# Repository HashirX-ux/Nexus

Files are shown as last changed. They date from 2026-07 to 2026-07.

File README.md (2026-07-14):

# Nexus


[]()
[]()
[]()
[]()

> A wireless 3x4 macropad i'm building to speed up my workflow. Hot-swap switches, per-key RGB, an OLED screen for status, and a rotary encoder for macros. Works wired or wireless.

---

## What is it?

Nexus is a custom 3x4 (12 key) macropad i designed mainly for shortcuts and repetitive commands i was tired of typing out. Built around a nice!nano v2 so it can do bluetooth LE, with USB-C as a backup if the battery dies or i just don't feel like pairing it again. 12 hot swap sockets, per key RGB underneath, an EC11 rotary encoder, and a little OLED that shows battery % and what its connected to.

(quick note to future me: the tagline used to say QMK somewhere, thats wrong, QMK doesnt really do BLE on this board properly so i switched to ZMK. fix that if you see it anywhere else)

## Why build it

Because reaching over to a full keyboard just to hit a macro or shortcut combo got annoying. If i build the layout, lighting and firmware myself it actually fits how i work instead of some generic layout someone else made.

---

## Status

Research + design phase mostly done, now just cleaning stuff up. Schematic and routing still need some touch ups here and there. Full build log with all the component reasoning is in [journal.md](./journal.md) if you wanna see why i picked what i picked (spoiler: half of it was just "this was in stock on lcsc").

- [x] Component research (MCU, diodes, switches, USB-C, passives)
- [x] Schematic design
- [x] PCB routing
- [x] PCB fabrication
- [x] Firmware pin mapping
- [x] Assembly
- [x] Case design

---

## Planned Specs

| Component | Choice |
|---|---|
| Layout | 3x4, 12 keys |
| MCU | nice!nano v2 (nRF52840) |
| Connectivity | Bluetooth LE (wireless) + USB-C (wired) |
| Switches | Hot-swap, MX-compatible (Kailh / Gateron / Cherry MX) |
| Matrix diodes | 1N4148 |
| RGB | Per-key, WS2812B |
| Encoder | EC11 rotary encoder |
| Display | OLED - battery % + connected device |
| Firmware | ZMK |
| USB | USB-C, USB 2.0 (480Mbps, 5V/500mA) |

---

```
```

Tried to keep this organized roughly the way hack club's [hardware codex shipping guide](https://codex.hackclub.com/shipping/101/) recommends - source files seperate from the manufacturing stuff so its easier for someone else to just grab and rebuild.

> If you dont wanna open kicad just to look at the board, theres a KiCanvas link so you can view it in browser:
> 

---

## Build log

Most of the actual thinking (datasheets i looked at, why i swapped parts, dumb mistakes i made along the way) is in [journal.md](./journal.md). Genuinely recommend reading it if your building something similar, its more useful than just staring at the BOM.

---

## Roadmap

1. finalize schematic (matrix wiring, rgb data line, oled i2c, encoder pins, reset button)
2. route + order the pcb
3. build/test zmk firmware against actual pin assignments (not just what i think they are)
4. design + print the case
5. assemble, flash, pair, hope it works first try

---

## How to build

### 1. order the PCB

1. go to [JLCPCB](https://jlcpcb.com)
2. upload [`Gerber.zip`](./Gerber.zip)
3. settings: 2 layer, FR-4, 1.6mm, HASL (or ENIG if your feeling fancy)
4. order the parts seperately with [`Nexus-BOM.csv`](./Nexus-BOM.csv) as your shopping list - digikey, lcsc, aliexpress all work fine

### 2. print the case

1. open [`cad/`](./cad) - print the `.stl` as is, or crack open the `.f3d` in fusion if you wanna change dimensions
2. 0.2mm layer height, ~20% infill is plenty, its just sitting on a desk not getting thrown around
3. test fit the plate BEFORE you solder anything, learned that one the hard way

### 3. assemble

1. solder the nice!nano v2 diodes resistors and other supprt parts per the [`pcb/`](./pcb) schematic
2. solder in the hot swap sockets, then just press the switches in, no soldering needed there
3. wire the oled, encoder and rgb chain per the pin notes in [`journal.md`](./journal.md)
4. seat the finished pcb intothe case

### 4. flash it

1. follow the zmk build steps in [`firmware/`](./firmware) (shield config + keymap)
2. double tap reset on the nice!nano to drop into UF2 bootloader mode
3. drag the compiled `.uf2` onto the drive that shows up
4. pair over bluetooth, or just plg it in over usb-c if you want wired

### 5. done

flip it over, look at the rgb for a bit, start binding macros. if somethings broken check [`journal.md`](./journal.md) first, saves time vs trying to figure it out from scratch again.

---

## BOM

ful parts list + links in [`Nexus-BOM.csv`](./Nexus-BOM.csv)

---

## Credits

- [ZMK Firmware](https://zmk.dev/)
- [nice!nano](https://nicekeyboards.com/nice-nano/)
- [nice!nano docs](https://nicekeyboards.com/docs/nice-nano/) - pinout + hardware ref, used this constantly

Built by **Hashir**

---

## License

MIT, see [LICENSE](./LICENSE)

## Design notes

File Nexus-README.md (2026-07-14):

# Nexus


[]()
[]()
[]()
[]()

> A wireless 3x4 mechanical macropad built to speed up your workflow. Hot-swap switches, per-key RGB, an OLED status screen, and a rotary encoder for macro control — wired or wireless.

---

## What is it?

Nexus is a custom 3x4 (12-key) macropad designed for productivity, shortcuts, and macros. It's built around a nice!nano v2 for wireless Bluetooth LE connectivity, with USB-C wired support as a fallback. It features 12 hot-swap key sockets under a per-key RGB array, plus a tactile EC11 rotary encoder and an OLED display for at-a-glance macro and connection status.

> **Note:** The original project tagline mentions QMK, but based on the build log the firmware direction is ZMK (needed for the nice!nano's BLE wireless support — QMK's BLE support doesn't target this board). Worth updating that tagline once you settle on a final direction.

## Why build it?

A dedicated macropad means shortcuts, macros, and repetitive commands live on their own set of keys — no reaching for a full keyboard's modifier combos. Building it from scratch means the layout, lighting, and firmware are all shaped around your own workflow.

---

## Status

This project is in the **research and design phase**. Component selection is done; PCB schematic and routing are still in progress. See [`journal.md`](./journal.md) for the full build log, including component research and reasoning for each part choice.

- [x] Component research (MCU, diodes, switches, USB-C, passives)
- [x] Schematic design
- [x] PCB routing
- [x] PCB fabrication
- [x] Firmware pin mapping
- [x] Assembly
- [x] Case design

---

## Planned Specs

| Component | Choice |
|---|---|
| Layout | 3x4, 12 keys |
| MCU | nice!nano v2 (nRF52840) |
| Connectivity | Bluetooth LE (wireless) + USB-C (wired) |
| Switches | Hot-swap, MX-compatible (Kailh / Gateron / Cherry MX) |
| Matrix diodes | 1N4148 |
| RGB | Per-key, WS2812B |
| Encoder | EC11 rotary encoder |
| Display | OLED — battery % and connected device status |
| Firmware | ZMK |
| USB | USB-C, USB 2.0 (480 Mbps, 5V/500mA) |

---

## Repository Structure

```
Nexus/
├── LICENSE
├── README.md
└── journal.md   # Build log: component research, decisions, reasoning
```

As the project progresses, this will likely grow to include:
```
├── pcb/         # KiCad schematic + PCB files
├── firmware/    # ZMK shield config, keymap, overlay
├── cad/         # Case design files
└── BOM.csv      # Bill of materials
```

---

## Build Log

The full day-by-day research process — component tradeoffs, datasheets referenced, and lessons learned along the way — lives in [`journal.md`](./journal.md). It's worth a read if you're building something similar and want the reasoning behind each part choice, not just the final BOM.

---

## Roadmap

1. Finalize schematic (matrix wiring, RGB data line, OLED I2C, encoder pins, reset button).
2. Route and order the PCB.
3. Build and test ZMK firmware against the real pin assignments.
4. Design and print/order the case.
5. Assemble, flash, and pair.

---

## Credits

- [ZMK Firmware](https://zmk.dev/) — open-source keyboard firmware
- [nice!nano](https://nicekeyboards.com/nice-nano/) — nRF52840 BLE module
- [nice!nano documentation](https://nicekeyboards.com/docs/nice-nano/) — pinout and hardware reference

Built by **Hashir**.

---

## License

Released under the [MIT License](./LICENSE).

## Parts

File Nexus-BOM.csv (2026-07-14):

Component | Spec | Qty | Est. Unit Price (USD) | Est. Line Total (USD) | Notes | Where to Source
MCU | nice!nano v2 (nRF52840) | 1 | $14.00 | $14.00 | BLE wireless + USB-C wired; brain of the board | nicekeyboards.com / AliExpress clone
Matrix diodes | 1N4148 (or 1N4148W SMD) | 12 | $0.03 | $0.36 | One per key; col2row direction per journal | LCSC / Mouser / AliExpress (packs of 100+)
Mechanical switches | MX-compatible (Kailh / Gateron / Cherry MX -- TBD) | 12 | $0.30 | $3.60 | Hot-swap so any 5-pin/3-pin MX switch works | Switch vendor of choice
Hot-swap sockets | Kailh hot-swap (MX compatible) | 12 | $0.10 | $1.20 | Sold in packs of 100+ | LCSC / AliExpress
Per-key RGB LEDs SK6812 Mini-E for lower profile) | 12 | $0.20 | $2.40 | One per key; confirm footprint (5050 vs Mini-E) before ordering PCB | LCSC / AliExpress
Rotary encoder | EC11 (with or without push switch) | 1 | $0.60 | $0.60 | Confirm detents/resolution before finalizing keymap | LCSC / AliExpress
OLED display | SSD1306 0.91" or 0.96" I2C (128x32 or 128x64) | 1 | $2.50 | $2.50 | Shows battery % and connected device per journal | AliExpress / Amazon
USB-C receptacle | 16-pin SMD (e.g. GCT USB4105 or equivalent) | 1 | $0.60 | $0.60 | For wired fallback mode | LCSC / AliExpress
Reset button | SMD tactile switch 3x4mm | 1 | $0.05 | $0.05 | Needed to put nice!nano into bootloader mode | LCSC / AliExpress
Decoupling capacitors | 100nF ceramic (0603/0805) | 4 | $0.02 | $0.08 | Power supply stabilization near MCU/OLED | LCSC / AliExpress
Bulk capacitor | 10uF ceramic or tantalum | 1 | $0.05 | $0.05 | Bulk decoupling for power rail | LCSC / AliExpress
LED data line resistor | 330-470 ohm (0603/0805) | 1 | $0.02 | $0.02 | Series resistor on WS2812B data line | LCSC / AliExpress
I2C pull-up resistors | 4.7k-10k ohm (0603/0805) | 2 | $0.02 | $0.04 | SDA/SCL pull-ups for OLED | LCSC / AliExpress
Battery (optional -- wireless use) | LiPo 3.7V 150-500mAh w/ JST PH2 | 1 | $4.00 | $4.00 | Not yet confirmed in journal -- needed if running BLE untethered | AliExpress / Adafruit
PCB fabrication | 2-layer FR-4 1.6mm HASL | 5 boards | $4.00 | $20.00 | Typical JLCPCB minimum order | JLCPCB / PCBWay
Keycaps | MX-compatible, 12-key set or pulled from a larger set | 12 | $0.30 | $3.60 | Blank or macro-labeled caps recommended | Any MX keycap vendor
Screws | M3 x 6-8mm | 8 | $0.05 | $0.40 | Case assembly | Local hardware / AliExpress
Standoffs | M3 x 4-6mm | 4 | $0.10 | $0.40 | Case assembly | Local hardware / AliExpress
TOTAL (est.) |  |  |  | ~$53.90 | Excludes case material/printing -- add once case design is finalized

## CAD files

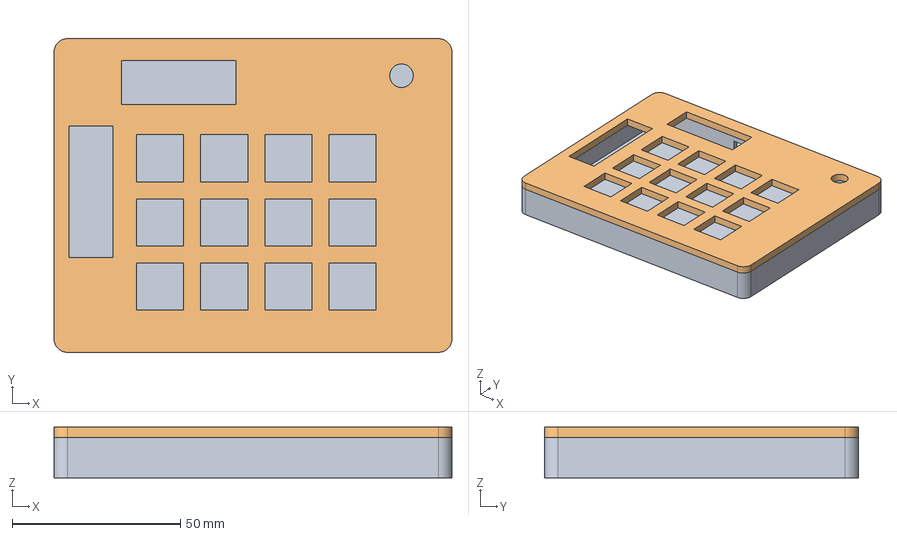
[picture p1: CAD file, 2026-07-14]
cad/Nexus-case.step
118.2 x 93.2 x 15.0 mm

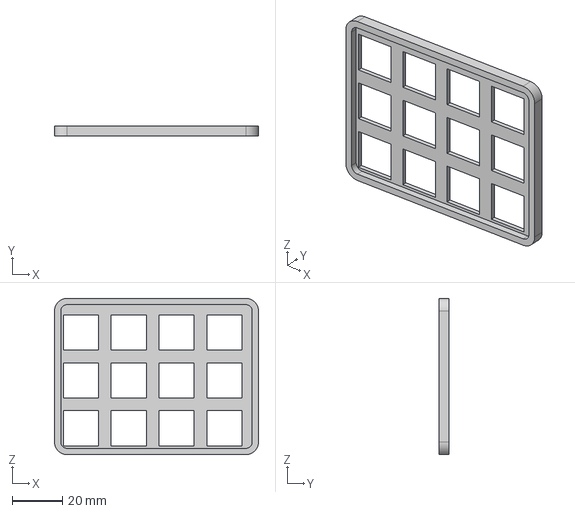
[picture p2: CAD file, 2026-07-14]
cad/Nexus-plate.step
81.3 x 4.10 x 62.2 mm

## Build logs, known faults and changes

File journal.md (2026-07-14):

# Project Journal

**Project Name:** Nexus  
**Start Date:** 2026-07-07  
**Status:** In Progress

## Overview
Nexus is a wireless 3x4 macropad built to optimize your workflow. It uses a nice!nano for Bluetooth LE. It features 12 hot-swap keys illuminated by a vibrant per-key RGB lighting array. A tactile EC11 rotary encoder and an OLED screen offer precise macro control. Powered by ZMK firmware, it brings seamless multi-device pairing anywhere you go.

## Recent Entries

### 2026-07-07 - First Journal Entry

**What I did today:**

I amn gonna start researching about my Macropad built for productivity named Nexus for it's components and elemensts. Since I have never created a macropad, It's gonna take a while.. 



Since I am making a productivity macropad, I need to use such MCU that supports wireless bluetooth capability. From My research I think nicenano-v2 would be best for my macropad 


<br>
> So I have summarized all the necessary components for a macropad. 
<br>
1- MCU -> nicenano!-v2 (It acts as the brain of the macropad and controls most all the operations)
<br>
2- Diodes(1N4148)
<br>
3- Mechanical Switches -> Gonna use Kalih or Gateron Switches and probably will consider Cherry MX)
<br>
USB-C(Gonna make it wired also) 
<br>
4- Capacitors and Resistors for Maintainance for powersupply

<br>
> I am gonna add some customs also for my macropad.
<br> 
1- OLED Display (Gonna show its battery percentage and connected devices) 
<br>
2- RGB lights(WS2812B) for Asthetics ifykyk
<br>
3- Rotary Encoder(EC11) No idea Why I am adding this (asthetics)
<br> 
<br>
Now I am gonna start researching about all the components one by one.. <br>
1- nicenano!<br>
Since nicenano has two versions I am gonna research about the latest one and use that.. <br>
Gonna use the official nicenano documentation for research about nicenan<br>
https://nicekeyboards.com/docs/nice-nano/<br>
This is how the nicenano pinouts look like: <br>

<br>
<br> 
So I gotta use ZMK firmware for my macropad since its wireless via bluetooth capability.. <br>
The Schematic looks intimidating but it's simple .. I guess<br>

<br>
<br>
Now I am gonna read some datasheets of the Diode (1N4148) specifically designed for macrpads and keybaords.. <br>
So these are the Diodes I am gonna be using<br>

<br> 
These diodes are really efficient for keebs and pads :D 
<br>
<br>
Now I am gonna research about the USB-C device that I am gonna use in my macropad cuase I wanna make my prodcutivity macroapd boht wired and wireless sor for wired capability I am gonna have to use USB-C<br>

Gonna use USB 2.0 as it provides 480 mps and takes 5V with 500mA

<br> 
Best Guide to Study USB-C:<br> 
https://www.ti.com/lit/eb/slyy228/slyy228.pdf?ts=1759892558029
<br>
Looks Like I am cooked :((

Now I think I have gained enough info about USB-C, Moving to the next componentttttttttt.
<br>
<br>
Now I am gonna start Researching about the capacitors and the resistors that are required for macropad and are essential for the Power Management accross the PCB<br>
Found a New component to research about: 

So bascially a crystal tells how fast the chip processes but I don't really have to build it since it comes pre-built with nicenano!-v2 chip so Im save :D:

<br>
<br>
Now I am gonna research about Capacitors that are needed in my macropad:<br>
Guess I don't need any caps at all except I think for my RGB lights.. 

<br>
<br>
I do have to also add a RESET button on my schematic for my nicenano! to go bootloader mode for my ZMK configuration: 

<br>
I also need some decoupling caps that are gonna stablise the power supply across the circuit: 

Fair Enough.. So I gotta maintain the power supply by at least adding one or more decoupling or bypass caps so that power accorss my Circuit stabilised in high and low voltages: 

<br>
Interesting.. 

<br>
Learned about a new concept called "impedance". Basically it refers to opposition a component or circuit offers to the AC: 

<br> 
Best Wbsites I have visited to study about Decoupling capacitors and value of 100nF and why is it important and what significance this specific value holds.. : 
<br>
https://pcbsync.com/100nf-capacitor/
<br>
https://learn.sparkfun.com/tutorials/capacitors/application-examples
<br>
<br> 
Now I am gonna start researching about the resistors that I need for my macropad:<br>
Looks like I don't really need the resisotrs for my macropad: 

<br>
But I think I do need them for my RGB lights for the key switches.. 

<br>
So the common resistors are 220 ohm and common caps are 100nF
<br>
nicenano! v2 gives the output login of 3.3V and take 5V from the USB input So i gotta be carefull before adding some resistors as they can limit the cuurent that is required by the RBG lights as they require much higher voltage(around 5V) so I only need to add like 1 resistors for every 2 RGB light to stablise the connection 
<br>
I also need a bulk Capacitor according to the lights I am gonna use which are RBG WS2812B

<br>
This is gonna store the voltage when the line surges or drops.. Interesting: 

<br>
THANK GODDD!!! IM SAVED.. I thought I would also need to build a voltage regulator for my macropad but I think I don't have to now :D

<br>
So the 330 ohms is the one I am targetting: 

<br>
<br> 
Now I am gonna research about the Rotary encoder I am gonna use for the macropad:<br>
So there are two rotary encoders am I am considering to use on of them.. One is PEC11R and the other encoder is EC11. I have researched and most of the resources recommend using the EC11 for a DIY- macropad cause it's the most industry standard and commonly used for macropads..

<br>
So this is the EC11 Rotary encoder: 

<br>
So the EC11 Rotary Encoder uses DC voltage of 3.3V which is perfect for my nicenano!-v2 MCU :D

<br>
<br> 
Now I am gonna start working on the KeySwitches of ny macropad:<br>
One of the best Guides I have read for the key  switches
https://www.theremingoat.com/blog/beginners-guide
<br>
So this is the Cherry MX switch. Looks pretty fine to me as it also metions that this key switch makes that "click" sound when you clikc it so I guess it's pretty cool :D

<br>
It seems pretty tempting to use Cherry MX keys.

<br>
Although Cherry MX keys looks a really good and reasonable choice, I am still gona search gonna search for more good and those "clicky" sound keys as I am reallt OBSSESED with them.. 
<br>
I think Kalih switches are also a really great Option to use but I gotta do a a liitle more research but I think i am considering to use Kailh swutches for my Macropad cause I think they look a little bit more beautifull than cheryy for some reason especially the kailh red switch is really attractive to use to I think I am gonna consider to use Kailh Switches and I have planned to use 12-key switches for my macropad and the matrix I am gonna use will be 3 x 4 :D
<br>
<br> 
Now I am gonna research about the battery that I am gonna use in my DIY-Macropad and for that I am gonna use nicenano! official documentation cause the have specified which battery to use to the Microcontroller.. 
<br>
https://nicekeyboards.com/docs/nice-nano/
<br>
Since I am also using the LED lights which is gonna take more power so I can't use the battery given in this documentation: 

<br>
Hence I am gonna use a 1500mAh battery for my DIY- Macropad. that is gonna help me maintain the electricty in the macropad when The bluetooth wireless capability is turned on .. 
<br>
This guide is really helpfull as it really helped to understand How schematics work and How I should design my own custom PCB and macropad :D. I didn't read it full though but gonna read it cuz its describes how pcb works and how to design their schematics :D<br>
https://github.com/ruiqimao/keyboard-pcb-guide#schematics
<br>
I researched about pull-up resistors and seems like I don't to place any external pullup resistors case nicenano! is TOOO GOATED!!!!!!!!. You can literally configure the power supply from the ZMK :D<br>
Here is the resource I used to read about the pullup resistors and it's really goated... :D<br>
https://learn.sparkfun.com/tutorials/pull-up-resistors<br> 
<br>
<br>
Since It's my firt time bulding a macropad so I am gonna read some of the guides on how to build that form absolute 00000000...
<br>
Found another guide on how to build a macropad form scratch. LET'S READDD<br>
https://medium.com/@timowielink/how-to-build-a-macropad-d5a154311c4c
<br>
The difference is I am gonna use a nicenano!-v2 microcontroller instead of ESP-32 MCU so I think there will be places Where I am gonna get stuck on This guide but let's hope for the best. :D
<br>
<br> 
Shoot.. I forgot to research about the OLED I am gonna use on my macropad. Lemme get that real quick:
<br>
I researched about which OLED to use and I came accross an OLED Which was also by nicenano! called niceview! and it seems pretty interesting since I have the same Microcontroller and as well as its OLED screen which it perfectlly suits.
<br>
https://nicekeyboards.com/docs/nice-view/pinout-schematic
<br>
This is the device I am planning to use as my OLED :D

<br>
And this is the schematic of the niceview!: 

<br>
This guy built a Macropad and open sources it:<br>
https://github.com/imchipwood/dumbpad
<br>
Found about these low profile switches .. Don't know what do they even do..

<br>
12C devices are quite interesting :D

<br>
A really good guide reguarding OLED and 12 protocol explanation..
<br>
https://blog.tinkercademy.com/deep-dive-into-the-i2c-oled-413fee46ada1
<br>
Ok I might consider using an OLED of 0.96": 

<br>
I am gonna search for some routing tips and I think I have found a great website for that.
<br>
https://www.pcbway.com/blog/PCB_Design_Layout/Common_Rules_for_PCB_Routing_29d86598.html
<br>
Didn't knew that greater loop would cause more heat and radiation during the routing of the PCB..

<br>
So i gotta make smaller loops in my routing so that I coukd avoid ekectromagnetic interference and unwanted noise.. 

<br>
I've found that de coupling capacitors help in reducing the electromagnetic interferance by maintaining the noise to signal ratio in the PCB so it's really a good practice to add bunch of those :D
and certainly 100nF is the best capacitor for balancing the pwoer in the PCB 
<br>
I also wanna learn about the 3D case design so I found an incredibally helpfull resouce to help me with that.. 
<br>
https://www.makerluis.com/step-by-step-guide-parametric-macro-pad-on-fusion-360/
<br>
I also found a video of this incredble Guy and he bascially gave a full tutorial on how one can design their own custom macropad case which is really helpfull. Hats off to this guy gng..
<br>
https://youtu.be/egOOHS-34-c?si=lpAW9fYHbgnp78mD
<br>
I think fusion 360 is currently the best 3d case software out there cause I have researched a lot on the 3d case for the macropad and Its showing me a fusion 360 tutorial every single time.. 
<br>
I Found the official hackclub's guide on designing a hackapad (Don't even know what that is) 
<br>
https://hackpad-v2-backup.pages.dev/guide#bottom
<br>
Since I am building a wired and wireless macropad I am gonna be using ZMK firmware for my macropad even though I have no idea what that even is in the first place So gonna research aobout it.. Wish me luck.. gang..
<br>
The ZMK docomentation is really helpfull for this :D
<br>
https://zmk.dev/docs/hardware
<br>
This guide is also really helpgull. Currently reading it ....
<br>
https://medium.com/@Myphis/zmk-firmware-unleashing-the-power-of-keyboard-customization-ed9fa9f8468e
<br>
So according to my summary QMK is for wired keyboards and ZMK is usually for wireless keyboards but ZMK can also be used for wired keyboards by having microcontrollers such as RP2040 wtc which I am not using for sure.. and I guess this is all I have to my today's journal and I am gonna write the next journal entry Tommorow :D

### 2026-10-08 - Second Journal Entry

**WHat I did Today:**
So Today I am gonna create the schematic of my Nexus aka macropad and its gonna be fun hopefully and I have already Researched about all the components that I need to build the schematic and Now I have to just make the schematic and then I'll be done with the schematic part. I am gonna build me schematic on KiCad.. 

<br>
I have created a keyboard type matrix for the macropad with a 3 x 4 matrix as I described earlier ny using a keyboard design guide from the resource https://www.nextpcb.com/blog/how-to-design-mechanical-keyboard-pcbs-with-kicad.. Looks cool to me. 

<br>
<br>
Now I am gonna start building the USB-C 2.0 16P schematic on the KiCad and it has a complete guide om how to set it up on the ncienano! official webiste and documentation so I am gonna read that real quick.. 
<br>
https://nicekeyboards.com/docs/nice-nano/pinout-schematic
<br>
I still can't figure out the function of the CC1 and CC2 pins of the USB-C 2.0 :((

<br>
Guess I am done with the USB-C configuration and Now I am gonna move to my next component..

<br>
<br>
Now with that being said I have somehow confiured my rotary encoder and have connected it to my Microcontroller and Now what it is gonna do is send signals to my macropad whenther it is getting pulled clockwise and will tell the microcontroller which in this case is nicenano! v2 to react in accordance to those signals 

<br>
<br>
Now I am gonna add a RESET switch and what it will gonna do is to make the Microcontroller, which in this case is nicenano, enter in a bootloader mode so that you can Literally drag and frop your ZMK firmware file in the USB device of the microcontrolle which will show up when it enters in the boot loader mode.. 
<br>

<br>
Just Found another helpfull resource for the Reset button guide :D
<br>
https://binaryupdates.com/switch-with-8051-microcontroller/
<br>
<br>
So Instead of using the classis 0.96" OLED, I used 0.91" OLED cause I couldn't find the symbol of the OLED 0.96" anywhere so I had to use OLED 0.91 but it's completely fine cause I guess 0.91" is more common among these DIY-macropads and I also cinfigured it in KiCad amd it's pretty simple :D

<br>
I have aslo creatd 2 decoupling caps for power management and they bascially manage the input power and high voltages that comes in the boara and these actually play a really vital role on the board :D

<br>
Now I am gonna add power management by thr battery cause my macropad is also wireless and as well as wired so I have researched and read what kind of battery Do I need form the nicenano"s official documentationa and its lithiu-Ion battery with 3.7V:
<br>
https://nicekeyboards.com/docs/nice-nano/
<br>
I think this is the battery that I need to store my power.. 

<br>
So I have used Conn_01x02 for my lithium battery and I also have set the capacity to 15500mAh which I think is decent for a macropad and I think it will makes my macropad atleast long lasting than those stupid Iphones(Saying that cause I can't afford one) 

<br>
For charging the battery I have used MCP73183-2-MC charger which is industry standard for Lithium-Ion batteries and It's also really easy to setup in the editing software which for me is KiCad :D

<br>
Nicenano! is super underated. I doon't even need a power regualtor to maintain my LED lights !!!!!!!!!!!!

<br>
Since my microcontroller which in this case is nicenano! outputs only 3.3V and my LEDs need like 5V of ouput voltage so I am gonna use a component which i found out which is 74AHCT123. This components bassically increases the voltage of the output 3.3 and makes it 5V and so its is really clear for my LEDs and I am gonna use this component: D

<br>
I also need to place a decoupling cap for my LED for it to be stable :D.. 

<br>
<br> 
Now I am gonna start Configuring out my MAIN BRAIN!!!! not literally I am talking about nicenano. I am gonna add all the new pins in the nicenano and then gonna configure it out.. 

<br>
I also gotta add the key matrix on my nicenano! chip.. 

<br>
Its kinda hard but I am still figuring it out.. 
<br>
Now I am gonna add some RGB Lights for my macropad keys but I gotta find how can I do that and study the function of the each pin of the LED so that I can easily connect it to my keys :D..

So this is how an LED is designed gng.. I think I am learning some great great stufffffff.. its just an LED brooo. anyways..

<br>
Done with the first Row gng. Now I gotta do 3 more rows so that it matches my matrix of 3 x 4. Then I'll have an LED for each of my key in the macropad and its gonna be dunn :D

<br>
Donw with 2 ROWSSS

<br>
So I have made thhe RGB key matrix and it looks really good to me :D. Now what's gonna happen is my keys of the macropad will have their own RBG lightining for them to shine.. YAYAYAYA

<br>
So I have also planned to add a buzzer so that it can also make those clicky sounds to make the macropad more satisfyign and addictive to use. SO I am GONNA MAKE YOU AN ADDICT HAHAHAHA

<br>
So Now I am gonna configure my whole schematic and make it look a more good and managable.. 
<br>
After Debugging SOO many erors running ERC like a madman, I finaly have 0 ERRORS!!!!!!!!!!!!!!!!!!

<br>
I still have 4 warnings but they dont matter gng.. hopefully

<br>
Gonna start arranging ts gng.. Wish me luck ...

<br>
LOOKS SOOO CLEAN... YAYYAYAYAY

<br>
It Even Looks more clean since I have named every Single component in the schematic.. 

<br>
GUYSSS ... After 11 DEVASTATING HRS.. I HAVE FINALYYY COMPLETED MY SCHEMATIC!!!!!!!!!!! YAYAYAYAYAYA



<br>
<br>
### 2026-09-07 - First Journal Entry

**What I did today:**
So Today I am gonna design the PCB of my macropad on the KiCad PCB editor and Its gonna be tough as I can see the diagram looks realy rough and I have to arrange EVERY single component of the schematic on this PCB editor sheet.. 

<br> 
I am gonna tsart by creating the keyboard matrix whohc consist of a push button of Kailh and RGB light and diodes and Caps of 100nF

<br>
So I am Finally Done with the keyboard matrix gng.. It look good to me.. I mean it's simple but its my first macropad.. DONT JUDGE MEEEEE!!!

<br>
MY FIRST MACROPAD DESIGN GANGGGGG!!!!!!!!!!!

<br>
Alomost done with the routing. I gotta route some more components and then I think I'll be done with the Riuting and then I am gonna do Design Rule check for my macropad and then FIX ALL the errors. So I think I have to invest like something around 5 hours more in it. It's taking sooooo long gng.. Wish me luck.. 

<br>
SOOO MANY ERRORSS!!!!!!!!!!!!!!!!!!

<br>
AYAYAYAYAYAYAYAYAYA!!!!!!!!!!!

<br>
Bro SOMEHOW I have 19 WARNINGS EVENTHOUGH I did absolutly nothing and here we go.. This app ragebaiting me fr...
****
<br>
All of this shoot just cause the components names are too "BIG" gng what the absolute hell 

<br>
I found github repository where all the necessary 3d models of keyboards.. IT'S SOOO GOATEDDDD!!!!!!!!
<br>
https://github.com/raulmoracode/Kiboar
<br>
UHHH .. HELLO????

<br>
FINALLY I CHANGED THE AXISSS.. god it was hard. It took sooo much accuracy to reach this lvl..


<br>
Gonna Use this github repository for my Kailh hotswap switches.. It tool sooooooooooooooooooo much browsing to search fot this golden repositor. It has all the 3D models gng :D 
<br>
https://github.com/raulmoracode/Kiboar
<br>
FINALY DONE WITH THE PCB!!!!!!!!!!!!!!!!!!!!!!!!!!!!!!!!!!!!!

<br>
<br>
### Second Journal Entry  2026-11-12

** What I did Today: **
So today I am gonna design my 3D case of my Macropad and I am gonna do that by using fusion 360 cause I have used it before and I know more than the basics so It should be easy.. WISH ME LUCK BOYSS.. 

<br>
So I Just created a 3d modela reference and so far it looks good to me
<br>
Sorry forgot to journal this part but I made the layout and its pretty decent i guesss
![Uploading image.png…]()

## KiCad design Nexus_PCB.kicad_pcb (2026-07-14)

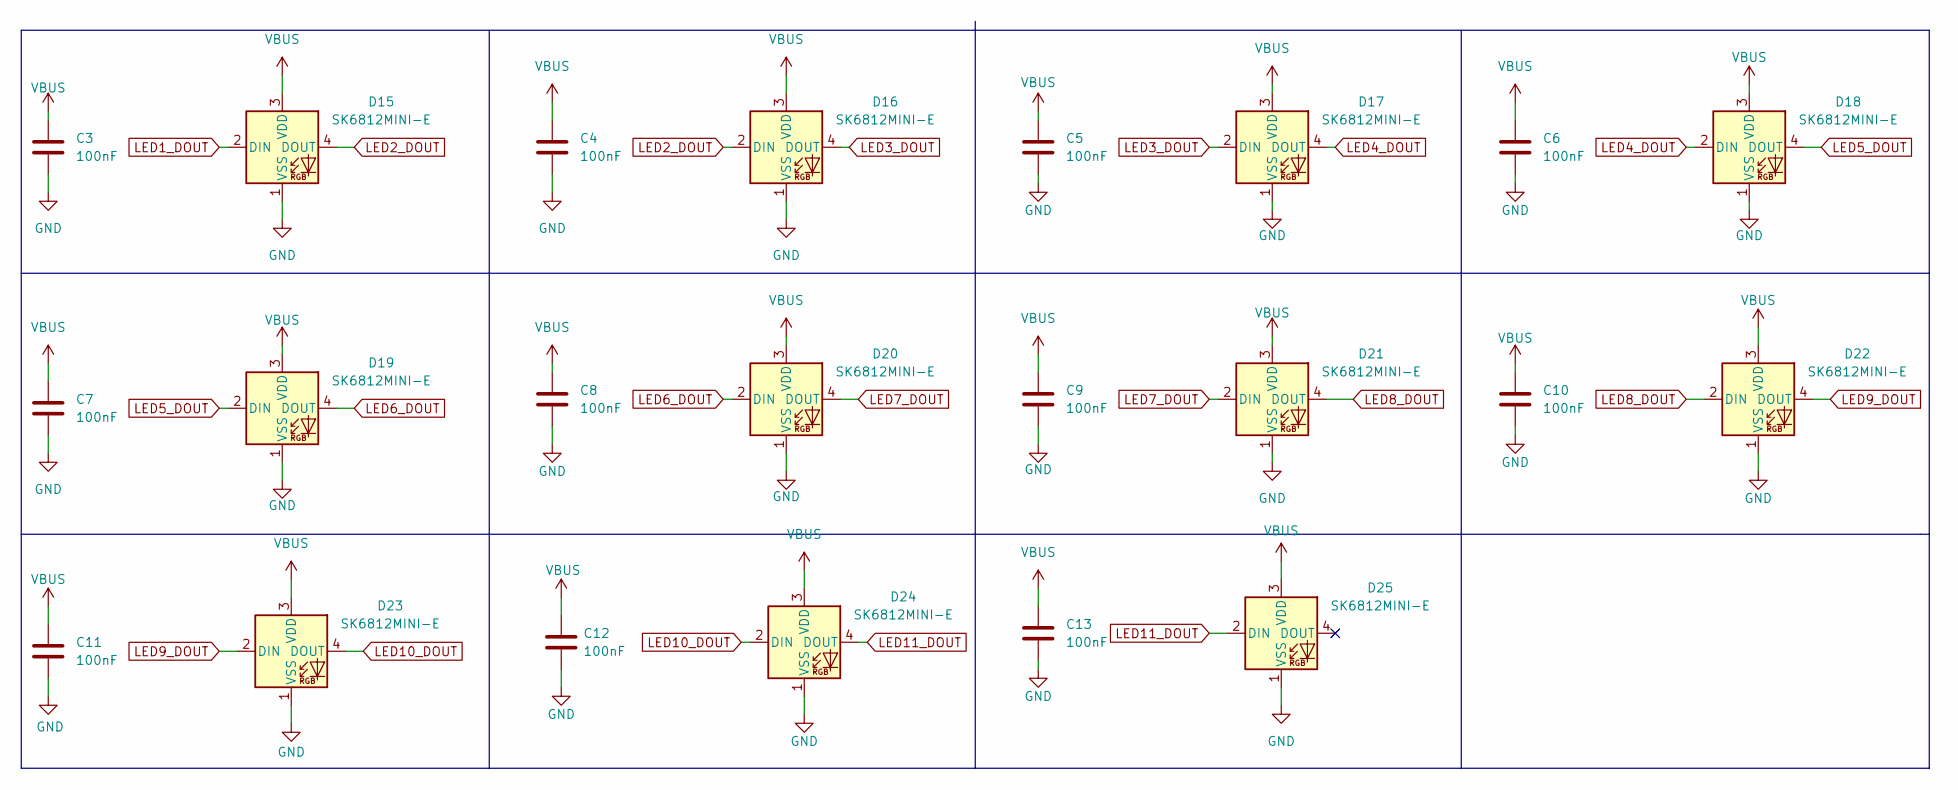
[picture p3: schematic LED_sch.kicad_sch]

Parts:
C3, C4, C5, C6, C7, C8, C9, C10, C11, C12, C13: 100nF; C_0805_2012Metric_Pad1.18x1.45mm_HandSolder
D15, D16, D17, D18, D19, D20, D21, D22, D23, D24, D25: SK6812MINI-E; LED_SK6812MINI-E_3.2x2.8mm_P1.5mm_ReverseMount

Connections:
GND: C3.2, C4.2, C5.2, C6.2, C7.2, C8.2, C9.2, C10.2, C11.2, C12.2, C13.2, D15.1 (VSS), D16.1 (VSS), D17.1 (VSS), D18.1 (VSS), D19.1 (VSS), D20.1 (VSS), D21.1 (VSS), D22.1 (VSS), D23.1 (VSS), D24.1 (VSS), D25.1 (VSS); also elsewhere on the board
LED1_DOUT: D15.2 (DIN); also elsewhere on the board
LED2_DOUT: D15.4 (DOUT), D16.2 (DIN)
LED3_DOUT: D16.4 (DOUT), D17.2 (DIN)
LED4_DOUT: D17.4 (DOUT), D18.2 (DIN)
LED5_DOUT: D18.4 (DOUT), D19.2 (DIN)
LED6_DOUT: D19.4 (DOUT), D20.2 (DIN)
LED7_DOUT: D20.4 (DOUT), D21.2 (DIN)
LED8_DOUT: D21.4 (DOUT), D22.2 (DIN)
LED9_DOUT: D22.4 (DOUT), D23.2 (DIN)
LED10_DOUT: D23.4 (DOUT), D24.2 (DIN)
LED11_DOUT: D24.4 (DOUT), D25.2 (DIN)
VBUS: C3.1, C4.1, C5.1, C6.1, C7.1, C8.1, C9.1, C10.1, C11.1, C12.1, C13.1, D15.3 (VDD), D16.3 (VDD), D17.3 (VDD), D18.3 (VDD), D19.3 (VDD), D20.3 (VDD), D21.3 (VDD), D22.3 (VDD), D23.3 (VDD), D24.3 (VDD), D25.3 (VDD); also elsewhere on the board

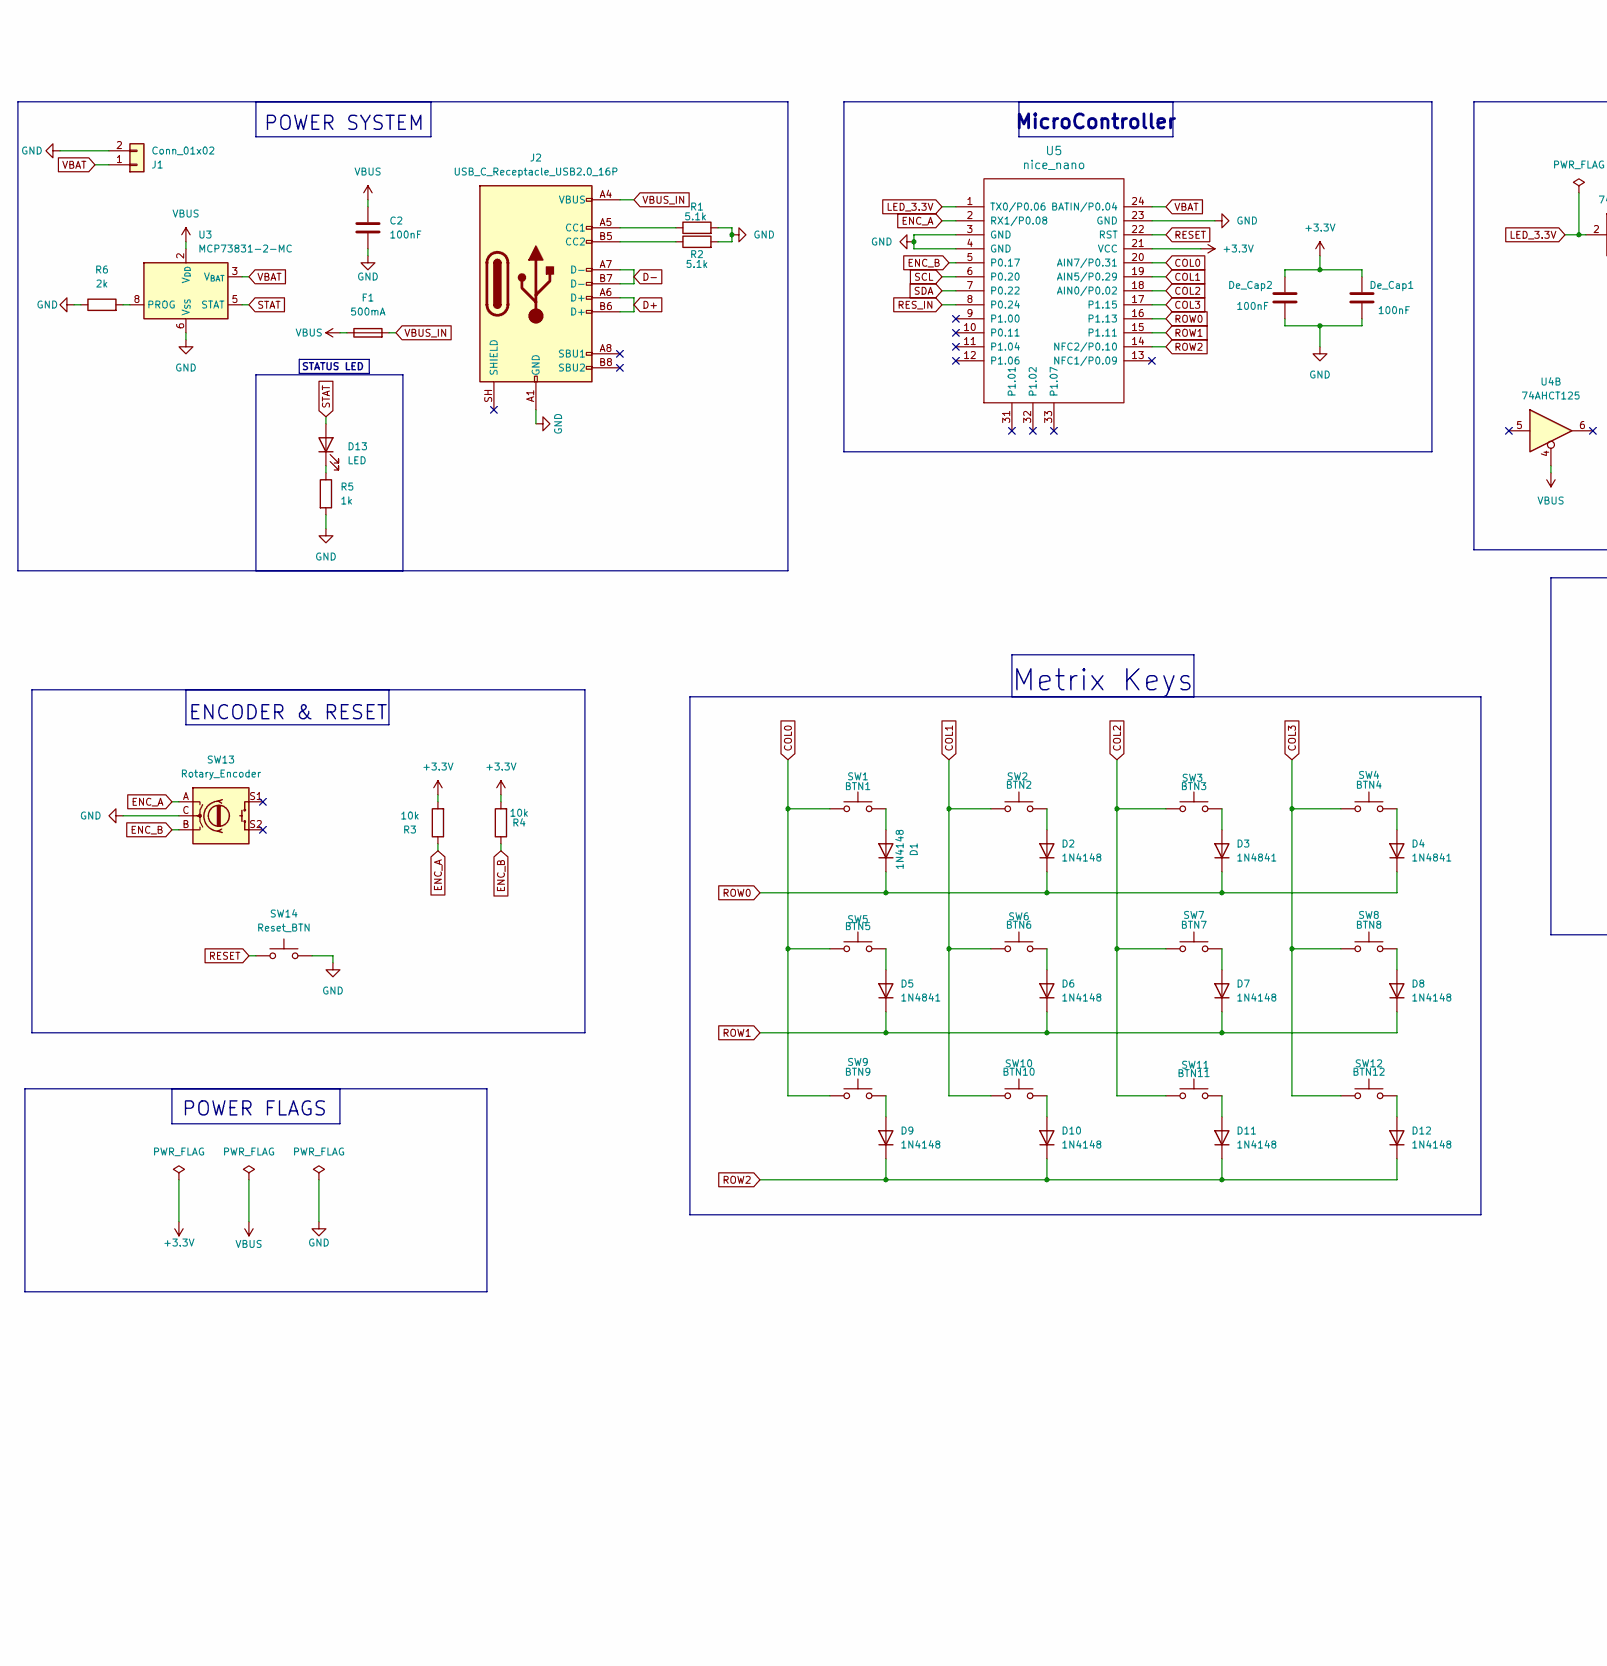
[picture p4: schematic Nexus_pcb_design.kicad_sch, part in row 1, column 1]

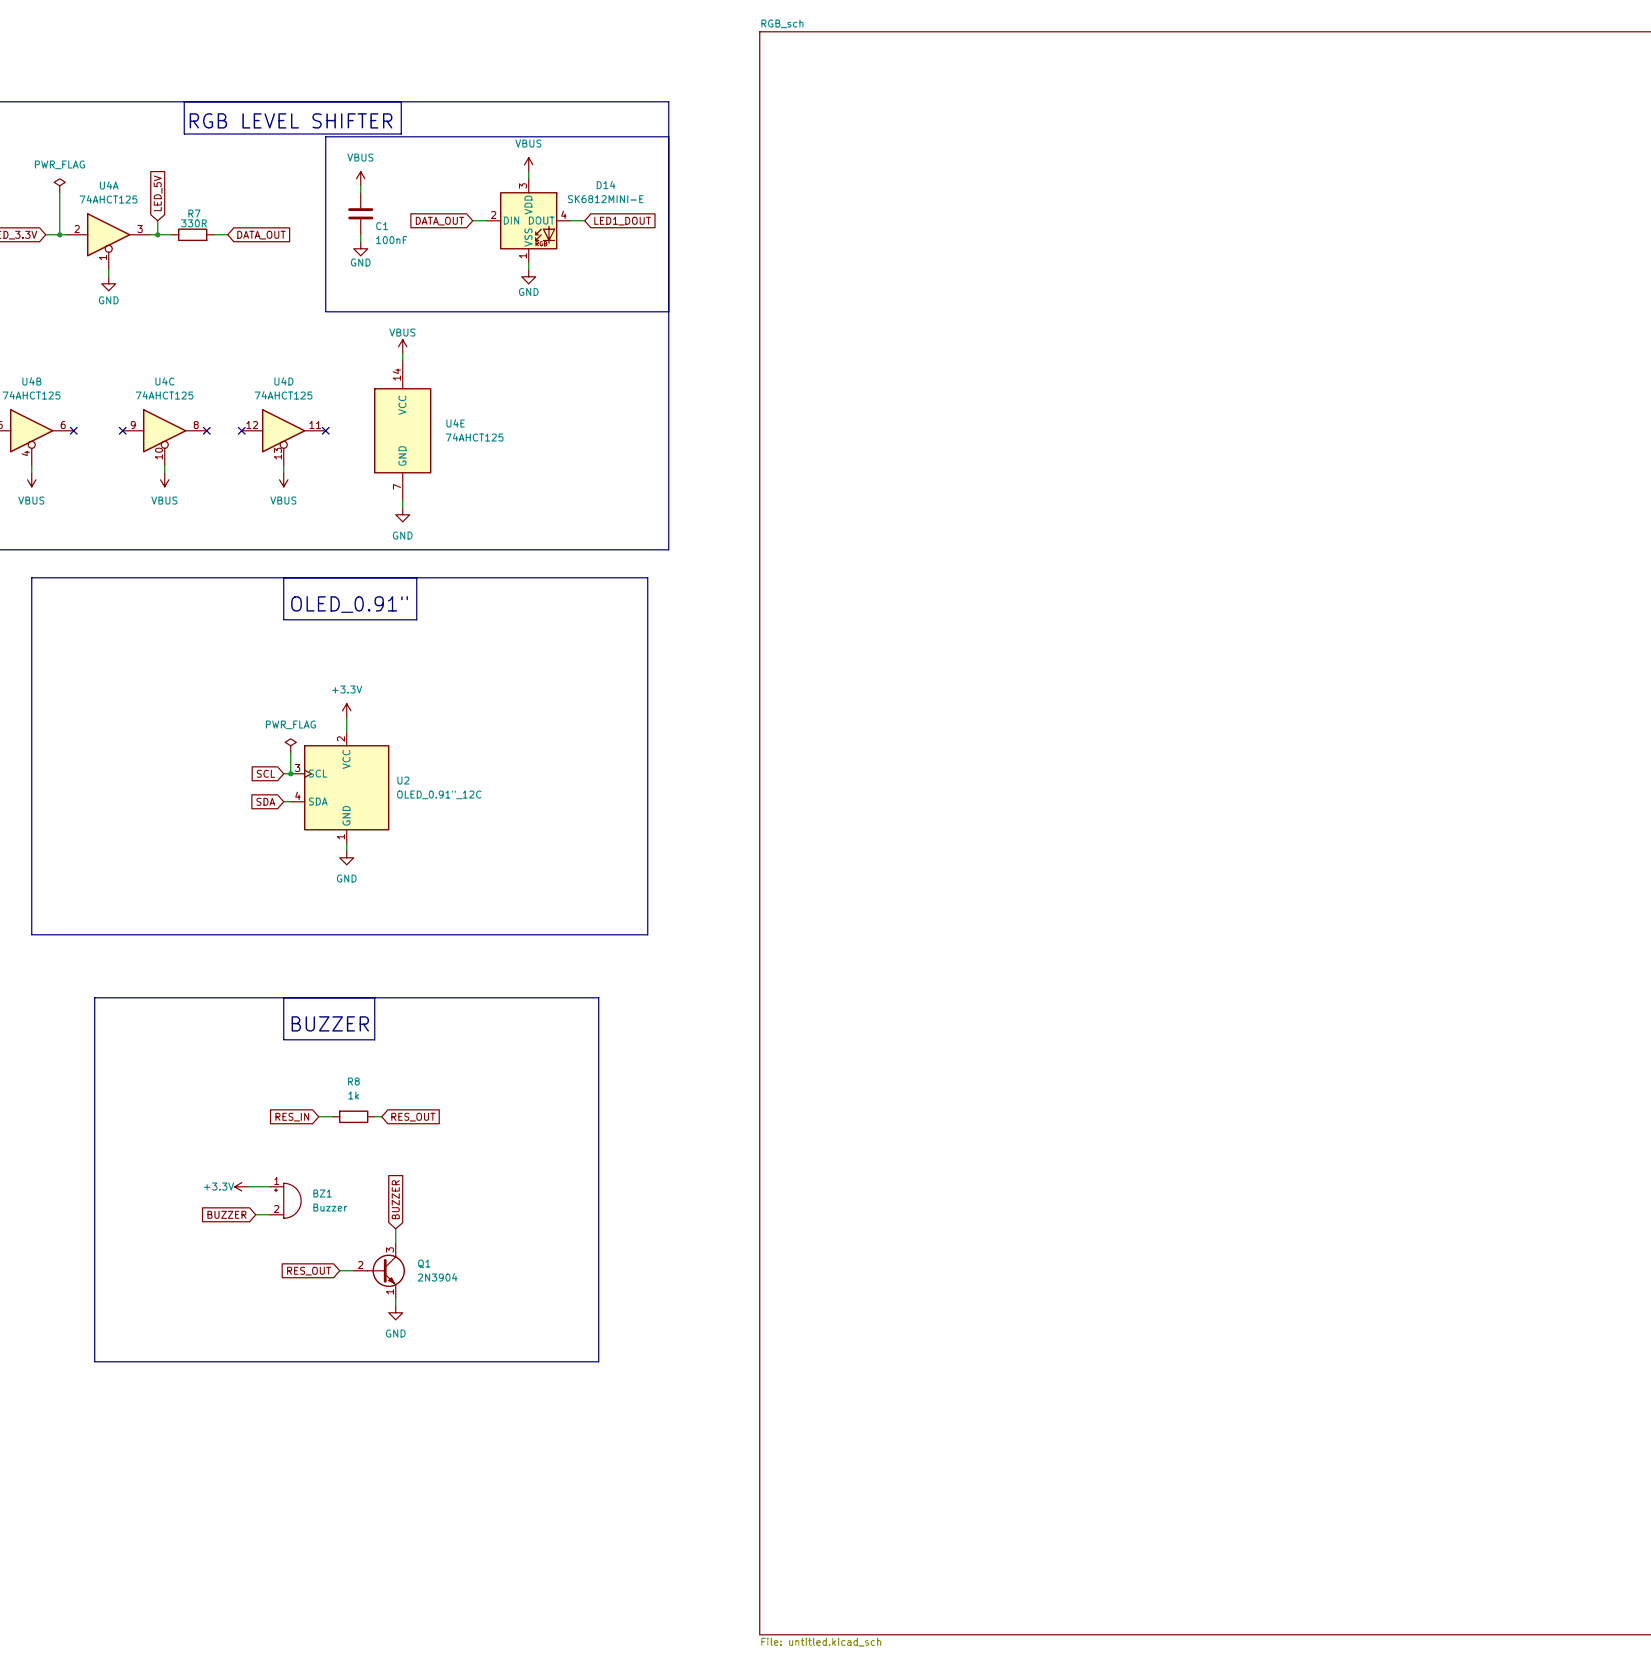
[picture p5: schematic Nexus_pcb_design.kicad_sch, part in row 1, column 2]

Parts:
BZ1: Buzzer; Buzzer_12x9.5RM7.6
C1, C2: 100nF; C_0805_2012Metric_Pad1.18x1.45mm_HandSolder
D1, D2, D6, D7, D8, D9, D10, D11, D12: 1N4148; D_SOD-123
D3, D4, D5: 1N4841; D_SOD-123
D13: LED; LED_0603_1608Metric
D14: SK6812MINI-E; LED_SK6812MINI-E_3.2x2.8mm_P1.5mm_ReverseMount
De_Cap1, De_Cap2: 100nF; C_0805_2012Metric_Pad1.18x1.45mm_HandSolder
F1: 500mA; Fuse_1206_3216Metric
J1: Conn_01x02; JST_PH_B2B-PH-K_1x02_P2.00mm_Vertical
J2: USB_C_Receptacle_USB2.0_16P; USB_C_Receptacle_GCT_USB4105-xx-A_16P_TopMnt_Horizontal
Q1: 2N3904; TO-92_Inline
R1, R2: 5.1k; R_0603_1608Metric_Pad0.98x0.95mm_HandSolder
R3, R4: 10k; R_0603_1608Metric_Pad0.98x0.95mm_HandSolder
R5: 1k; R_1206_3216Metric
R6: 2k; R_0603_1608Metric_Pad0.98x0.95mm_HandSolder
R7: 330R; R_0603_1608Metric_Pad0.98x0.95mm_HandSolder
R8: 1k; R_0805_2012Metric
SW1: BTN1; SW_Hotswap_Kailh_MX_1.00u
SW2: BTN2; SW_Hotswap_Kailh_MX_1.00u
SW3: BTN3; SW_Hotswap_Kailh_MX_1.00u
SW4: BTN4; SW_Hotswap_Kailh_MX_1.00u
SW5: BTN5; SW_Hotswap_Kailh_MX_1.00u
SW6: BTN6; SW_Hotswap_Kailh_MX_1.00u
SW7: BTN7; SW_Hotswap_Kailh_MX_1.00u
SW8: BTN8; SW_Hotswap_Kailh_MX_1.00u
SW9: BTN9; SW_Hotswap_Kailh_MX_1.00u
SW10: BTN10; SW_Hotswap_Kailh_MX_1.00u
SW11: BTN11; SW_Hotswap_Kailh_MX_1.00u
SW12: BTN12; SW_Hotswap_Kailh_MX_1.00u
SW13: Rotary_Encoder; RotaryEncoder_Alps_EC11E-Switch_Vertical_H20mm_MountingHoles
SW14: Reset_BTN; SW_Push_1P1T_NO_CK_KMR2
U2: OLED_0.91"_12C; ER_OLEDM0.91_1x-I2C
U3: MCP73831-2-MC; DFN-8-1EP_3x2mm_P0.5mm_EP1.7x1.4mm
U4: 74AHCT125; TSSOP-14_4.4x5mm_P0.65mm
U5: nice_nano

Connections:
+3.3V: BZ1.1 (+), De_Cap1.1, De_Cap2.1, R3.2, R4.2, U2.2 (VCC), U5.21 (VCC)
BUZZER: BZ1.2 (-), Q1.3 (C)
COL0: SW1.1, SW5.1, SW9.1, U5.20 (AIN7/P0.31)
COL1: SW2.1, SW6.1, SW10.1, U5.19 (AIN5/P0.29)
COL2: SW3.1, SW7.1, SW11.1, U5.18 (AIN0/P0.02)
COL3: SW4.1, SW8.1, SW12.1, U5.17 (P1.15)
D+: J2.A6 (D+), J2.B6 (D+)
D-: J2.A7 (D-), J2.B7 (D-)
DATA_OUT: D14.2 (DIN), R7.2
ENC_A: R3.1, SW13.A, U5.2 (RX1/P0.08)
ENC_B: R4.1, SW13.B, U5.5 (P0.17)
GND: C1.2, C2.2, D14.1 (VSS), De_Cap1.2, De_Cap2.2, J1.2, J2.A1 (GND), J2.A12 (GND), J2.B1 (GND), J2.B12 (GND), Q1.1 (E), R1.2, R2.2, R5.2, R6.1, SW13.C, SW14.2, U2.1 (GND), U3.6 (V_{SS}), U4.1, U4.7 (GND), U5.3 (GND), U5.4 (GND), U5.23 (GND); also elsewhere on the board
LED1_DOUT: D14.4 (DOUT); also elsewhere on the board
LED_3.3V: U4.2, U5.1 (TX0/P0.06)
LED_5V: R7.1, U4.3
unnamed: D1.2 (A), SW1.2
unnamed: D2.2 (A), SW2.2
unnamed: D3.2 (A), SW3.2
unnamed: D4.2 (A), SW4.2
unnamed: D5.2 (A), SW5.2
unnamed: D6.2 (A), SW6.2
unnamed: D7.2 (A), SW7.2
unnamed: D8.2 (A), SW8.2
unnamed: D9.2 (A), SW9.2
unnamed: D10.2 (A), SW10.2
unnamed: D11.2 (A), SW11.2
unnamed: D12.2 (A), SW12.2
unnamed: D13.1 (K), R5.1
unnamed: J2.A5 (CC1), R1.1
unnamed: J2.B5 (CC2), R2.1
unnamed: R6.2, U3.8 (PROG)
RESET: SW14.1, U5.22 (RST)
RES_IN: R8.2, U5.8 (P0.24)
RES_OUT: Q1.2 (B), R8.1
ROW0: D1.1 (K), D2.1 (K), D3.1 (K), D4.1 (K), U5.16 (P1.13)
ROW1: D5.1 (K), D6.1 (K), D7.1 (K), D8.1 (K), U5.15 (P1.11)
ROW2: D9.1 (K), D10.1 (K), D11.1 (K), D12.1 (K), U5.14 (NFC2/P0.10)
SCL: U2.3 (SCL), U5.6 (P0.20)
SDA: U2.4 (SDA), U5.7 (P0.22)
STAT: D13.2 (A), U3.5 (STAT)
VBAT: J1.1, U3.3 (V_{BAT}), U3.4 (V_{BAT}), U5.24 (BATIN/P0.04)
VBUS: C1.1, C2.1, D14.3 (VDD), F1.1, U3.1 (V_{DD}), U3.2 (V_{DD}), U4.4, U4.10, U4.13, U4.14 (VCC); also elsewhere on the board
VBUS_IN: F1.2, J2.A4 (VBUS), J2.A9 (VBUS), J2.B4 (VBUS), J2.B9 (VBUS)

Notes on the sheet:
STATUS LED
BUZZER
ENCODER & RESET
POWER FLAGS
Metrix Keys
POWER SYSTEM
RGB LEVEL SHIFTER
OLED_0.91"
MicroController

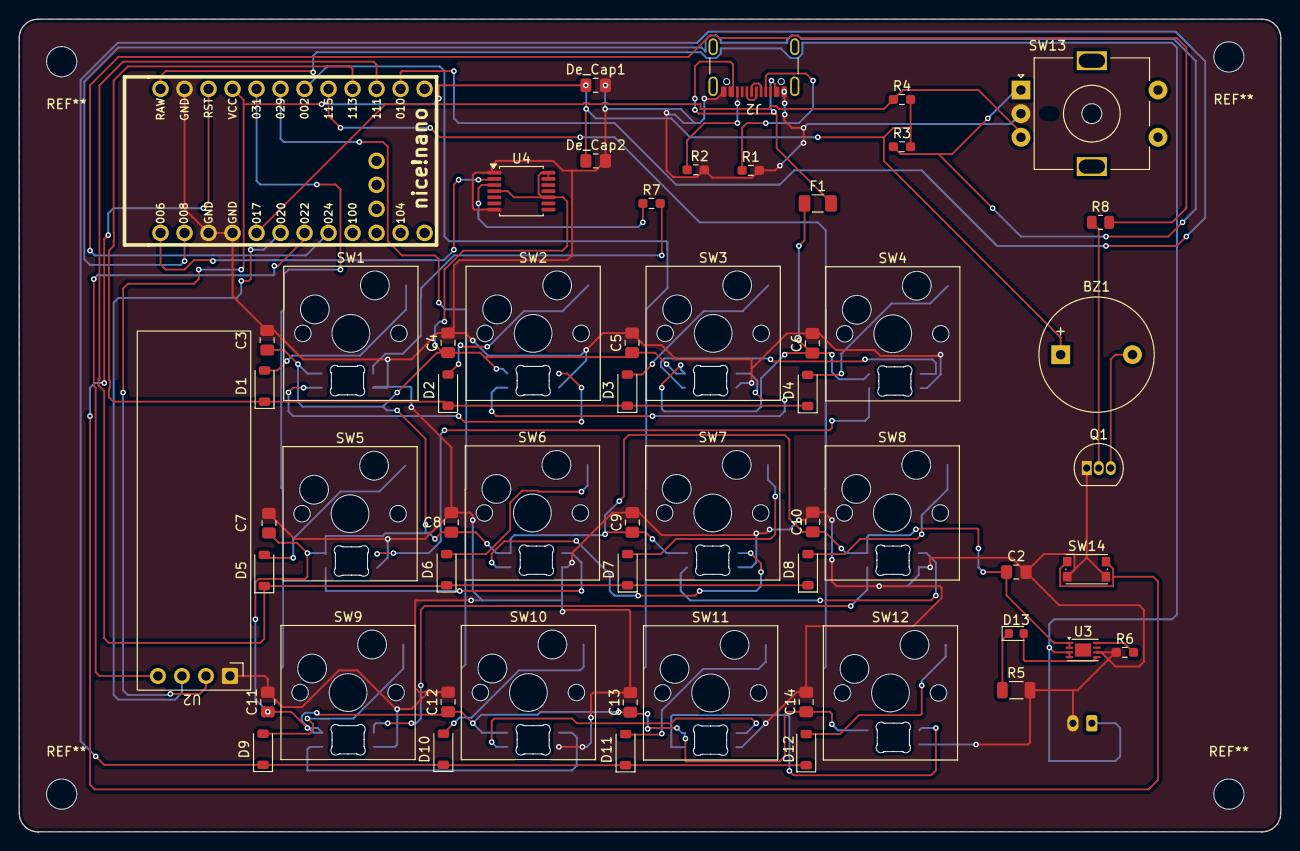
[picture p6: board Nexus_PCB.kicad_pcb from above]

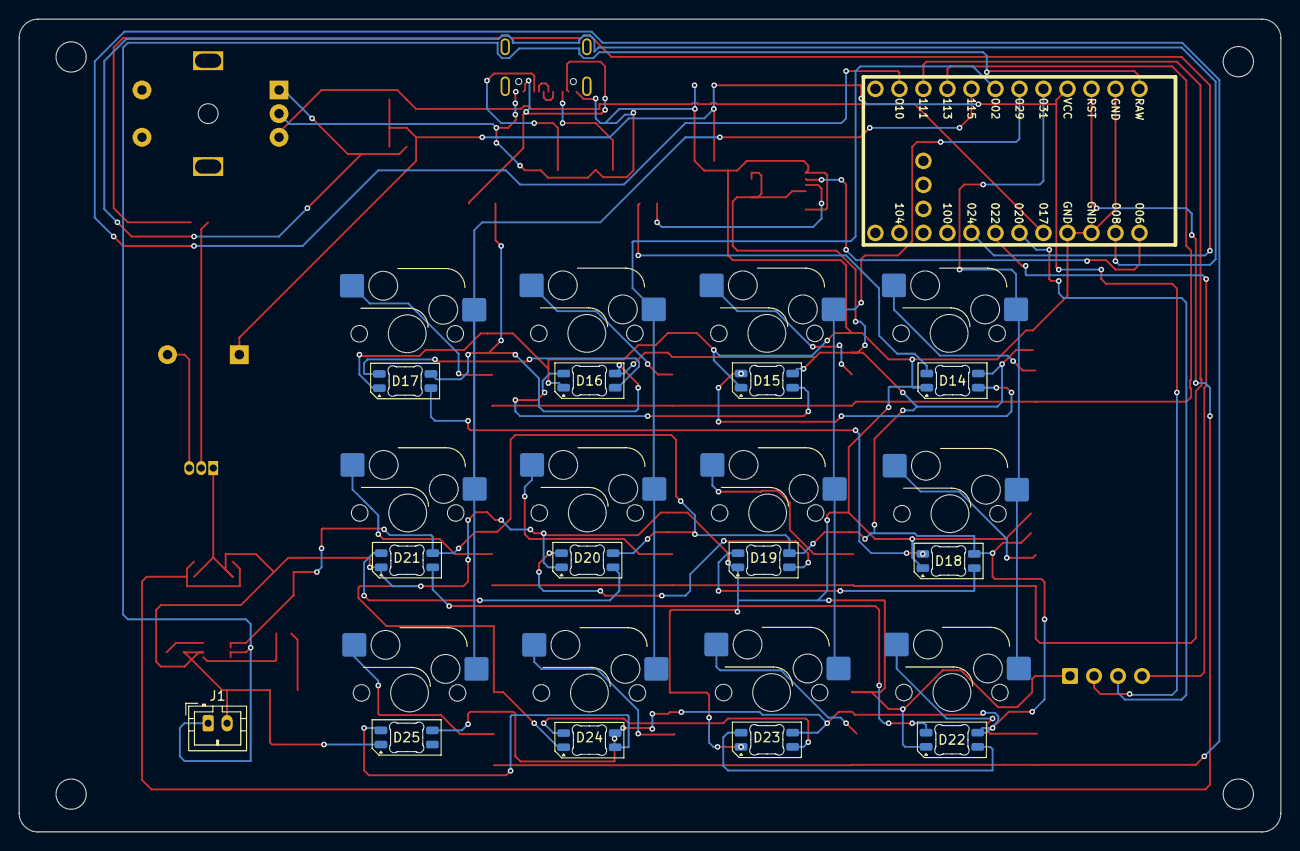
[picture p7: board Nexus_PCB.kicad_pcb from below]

Board: 2 copper layers, 133.5 x 86.0 mm, 71 parts (13 on the bottom side), 53 nets.

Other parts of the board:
C14: 100nF; C_0805_2012Metric_Pad1.18x1.45mm_HandSolder

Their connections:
GND: C14.2; also elsewhere on the board
VBUS: C14.1; also elsewhere on the board

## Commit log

2026-07-08 Revise component list for macropad build
    Updated the list of components for the macropad, including details about the OLED display, RGB lights, and rotary encoder.
2026-07-08 Update journal with ZMK firmware and diode details
    Added information about using ZMK firmware and diode datasheets for macropad.
2026-07-08 Update journal with diode and USB-C details
    Added information about diodes and USB-C device for macropad.
2026-07-08 Update journal with research on resistors for macropad
    Added notes on resistors and their necessity for the macropad and RGB lights.
2026-07-08 Add details on common resistors and capacitors
    Added information about common resistors and capacitors.
2026-07-08 Update journal with nicenano! v2 details
    Corrected and expanded the explanation regarding the nicenano! v2 output voltage and resistor usage for RGB lights.
2026-07-08 Document bulk capacitor requirements for RGB lights
    Added notes on using bulk capacitors for RGB WS2812B lights and included images for reference.
2026-07-09 Document EC11 Rotary Encoder details and images
    Added information about the EC11 Rotary Encoder and its compatibility with the nicenano!-v2 MCU. Included images for better illustration.
2026-07-09 Revise text on Cherry MX and Kalih switches
    Corrected typos and improved clarity in the text about keyboard switches.
2026-07-09 Update journal entry on keyboard switches
    Revised text for clarity and corrected typos regarding switch options for the macropad.
2026-07-09 Document battery research for DIY Macropad
    Added information about battery research for DIY Macropad, including reference to NiceNano documentation and battery specifications.
2026-07-09 Update journal with pull-up resistor research
    Added information about pull-up resistors and resources.
2026-07-09 Document research on pull-up resistors and macropad build
    Added notes about researching pull-up resistors and building a macropad.
2026-07-09 Document OLED research for macropad
    Added research notes about the OLED for the macropad, including a link to the device's documentation and an image.
2026-07-09 Update journal with OLED and PCB routing information
    Added new content about OLED usage and PCB routing tips with relevant links and images.
2026-07-09 Document progress on macropad schematic and USB-C setup
    Added details about creating a keyboard matrix and starting the USB-C schematic.
2026-07-09 Document USB-C and rotary encoder progress
    Added updates about USB-C configuration and rotary encoder setup.
2026-07-09 Update journal with rotary encoder and RESET switch details
    Added information about configuring a rotary encoder and planned RESET switch functionality for the microcontroller.
2026-07-09 Update journal with USB-C schematic and encoder details
    Added details about building the USB-C schematic and configuring the rotary encoder. Included information on the RESET switch functionality and a helpful resource for the reset button guide.
2026-07-10 Document decoupling capacitors for power management
    Added information about decoupling capacitors for power management in the project.
2026-07-10 Update journal with power management notes
    Added details about power management and battery research for the macropad.
2026-07-10 Document battery choice for macropad power management
    Added information about battery selection for power management in the macropad.
2026-07-10 Update journal with Nicenano! insights
    Added comments about the Nicenano! and its efficiency for LED lights.
2026-07-10 Mention decoupling capacitor for LED stability
    Added a note about the need for a decoupling capacitor for LED stability.
2026-07-10 Update journal with RGB lights and LED design notes
    Added new content about RGB lights for macropad keys and learning about LED design.
2026-07-10 Update journal with buzzer plans and schematic notes
    Added plans for a buzzer and schematic improvements.
2026-07-10 Update journal with progress on macropad project
    Added updates about buzzer integration and schematic configuration. Celebrated achieving zero errors in ERC after debugging.
2026-07-11 Add first journal entry about PCB design
    Added first journal entry detailing the PCB design process for a macropad, including images and descriptions of components.
2026-07-14 Add KiCad PCB + schematic, Gerber files, Fusion 360 CAD (STEP), firmware, and BOM
    [LED_sch.kicad_sch, Nexus-BOM.csv, Nexus-case.step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]
